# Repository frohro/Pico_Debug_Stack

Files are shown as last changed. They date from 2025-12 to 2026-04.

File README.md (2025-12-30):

# Raspberry Pi Pico Debug Stack

**A professional-grade hardware interposer for debugging, analyzing, and validating Raspberry Pi Pico projects.**
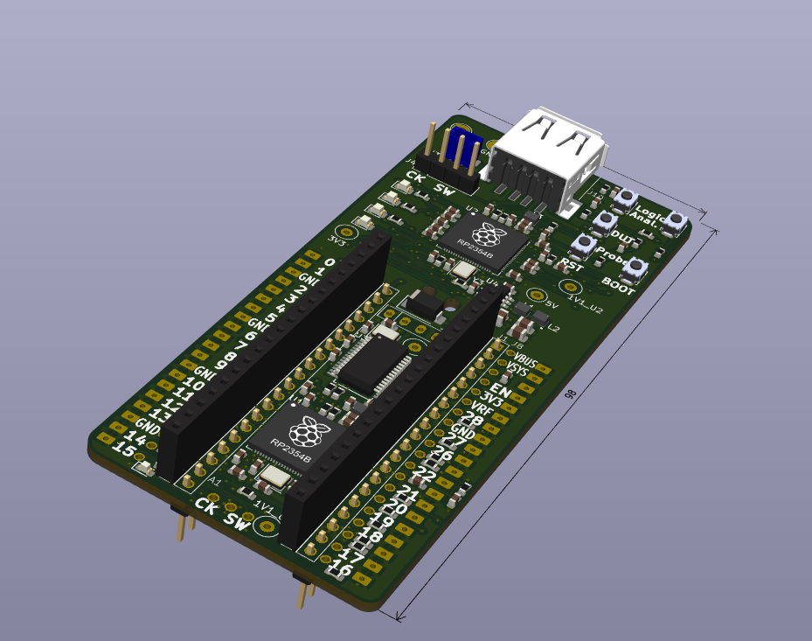
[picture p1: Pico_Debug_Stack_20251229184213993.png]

 

## Overview

The **Pico Debug Stack** is a "Man-in-the-Middle" Debug tool designed to eliminate the wiring mess typically associated with hardware debugging.

It acts as a hardware shim:
1.  Unplug your **Target Pico (DUT)** from your project motherboard.
2.  Plug the **Debug Stack** into your motherboard.
3.  Plug your **Target Pico** into the socket on top of the Debug Stack.

With a single USB connection to your PC, you instantly gain access to a full suite of hardware analysis tools connected directly to the DUT's pins, with no breadboards or jumper wires required.

## Key Features

*   **Integrated Logic Analysis:** Onboard **RP2354B** (with 2MB internal flash) running **[Dr. Gusman's Logic Analyzer](https://github.com/gusmanb/logicanalyzer)**. Capable of capturing high-speed signals (SPI, I2C, UART, I2S) from the DUT.
*   **Integrated Debug Probe:** Onboard **RP2354B** (with 2MB internal flash) running **[Yapicoprobe](https://github.com/rgrr/yapicoprobe)** (compatible with standard CMSIS-DAP/Picoprobe). Provides SWD debugging (Step, Pause, Breakpoints) and a UART console.
*   **Hardware Stimulus:** The Debug Probe is hardwired to the DUT's GPIOs via protection resistors, allowing you to inject signals or simulate sensors programmatically.
*   **Integrated USB Hub:** An onboard **GL850G USB Hub** manages all devices via a single USB-C connection. It provides:
    *   Internal link to the Logic Analyzer.
    *   Internal link to the Debug Probe.
    *   **Two auxiliary USB-A ports** (Stacked Connector J10) for connecting the Target Pico or other peripherals.
*   **Robust Power:** A **2A Synchronous Buck Converter (MT2492)** ensures ample power for the Debug Stack and the Target Pico.
*   **Universal Compatibility:** Supports Raspberry Pi Pico, Pico W, Pico 2, and Pico 2W.
*   **Safety First:** 330Ω series resistors protect all GPIO connections between the Analyzer, Probe, and DUT.

## Hardware Architecture

The board consists of three main controllers:

1.  **U1 (Logic Analyzer):** An **RP2354B** dedicated to monitoring DUT GPIOs.
2.  **U2 (Debug Probe):** An **RP2354B** handling SWD communication and Stimulus generation.
3.  **U3 (USB Hub):** A **GL850G** providing connectivity to U1, U2, and the auxiliary ports.

### The Stack Physical Layout
*   **Top:** Socket for DUT (Pico H footprint).
*   **Middle:** The Debug Stack PCB (Analyzer + Probe + Hub).
*   **Bottom:** Male Headers (plugs into your original project).

### Important Note on DUT USB
The **Target Pico's USB data lines (D+/D-)** are **NOT** routed through the stack headers to the Hub automatically.
*   **Debug/Analysis:** Works instantly via the shim headers.
*   **Target USB Data:** If your Target Pico runs code that requires USB connectivity (e.g., TinyUSB), you must use a short USB cable to connect the Target Pico's USB port to one of the **Auxiliary USB-A ports** on the Debug Stack.

## Software & Firmware

To use this board, the onboard RP2354s must be flashed with the following firmware:

*   **Logic Analyzer (U1):** [Download Dr. Gusman's LogicAnalyzer Firmware](https://github.com/gusmanb/logicanalyzer) Ensure you use the RP2350 build for this board.  Instead of shorting GPIO0 and GPIO1 to do burst capture, GPIO30 is connected to GPIO29.  These are  settings in the LogicAnalyzer_BoardSettings.h.  I will put the .uF2 file for this LogicAnalyzer on GitHub.
*   **Debug Probe (U2):** [Download Yapicoprobe Firmware](https://github.com/rgrr/yapicoprobe) (or the official Raspberry Pi `debugprobe` firmware).  

## Using the Stimulus Features

One of the most powerful features of this board is the ability to use the **Debug Probe (U2)** to "exercise" the **DUT**. Because the Probe's GPIOs are wired to the DUT's GPIOs (via 330Ω resistors), you can write software for the Probe to simulate external hardware.

### Concept
Instead of physically wiring a button or a sensor to your project to test it, you can tell the Probe to "pull Pin 15 High" or "Send a pulse on Pin 2".

### Example: Writing Stimulus Software
*The following is a MicroPython example. You can run this on the **Debug Probe (U2)** to test the DUT.*

**Scenario:** Your DUT code waits for a button press on `GP15` and then blinks an LED. You want to automate testing this.

1.  Flash **MicroPython** onto the **Debug Probe (U2)** (temporarily replacing the probe firmware).
2.  Run this script on U2:

```python
import machine
import time

# Note: Check the schematic for the specific mapping between Probe GPIO and DUT GPIO
# The mapping is scrambled to optimize PCB routing.
stimulus_pin = machine.Pin(15, machine.Pin.OUT) 

print("Starting Stimulus Test...")

while True:
    print("Simulating Button Press (High)...")
    stimulus_pin.value(1)
    time.sleep(0.5) # Hold for 500ms
    
    print("Simulating Release (Low)...")
    stimulus_pin.value(0)
    time.sleep(2.0) # Wait 2 seconds before next test
```

### Advanced Stimulus (C/C++)
For high-speed protocol simulation (e.g., simulating an SPI sensor sending data to the DUT), you should write a C/C++ program for the Probe using the Pico SDK.

**Skeleton Code for `main.c` on the Probe:**

```c
#include "pico/stdlib.h"
#include "hardware/gpio.h"

// Map of Probe Pins to DUT Pins (Refer to Schematic)
#define STIMULUS_PIN_A  10 
#define STIMULUS_PIN_B  11

void generate_fake_sensor_data() {
    // Bit-bang a protocol or toggle pins
    gpio_put(STIMULUS_PIN_A, 1);
    sleep_us(10);
    gpio_put(STIMULUS_PIN_A, 0);
}

int main() {
    stdio_init_all();
    
    gpio_init(STIMULUS_PIN_A);
    gpio_set_dir(STIMULUS_PIN_A, GPIO_OUT);

    while (1) {
        // Wait for a command from PC, or just run a loop
        generate_fake_sensor_data();
        sleep_ms(100);
    }
}
```
## Kicad Project
This Kicad project uses the CDFER [JLCPCB Library](https://github.com/CDFER/JLCPCB-Kicad-Library).  If you don't install it, the rules checker in EESchema will bark at you.  After installing it, you have to quit Kicad and start again.

## Setup Instructions

1.  **Assembly:** Ensure U1 and U2 are flashed with their respective firmware.
2.  **Connection:** Plug the board into your PC via the USB-C port labeled `USB IN`.
3.  **Drivers:**
    *   **Analyzer:** Open Dr. Gusman's software (or Sigrok PulseView) and connect to the Logic Analyzer device.
    *   **Probe:** In VS Code (or your IDE), select the CMSIS-DAP interface for the Debug Probe.
4.  **Hardware Install:**
    *   Plug the Debug Stack into your project board.
    *   Plug your Pico H (DUT) into the socket on the Debug Stack.

## License

Designed by Rob Frohne, Walla Walla University.
Open Source Hardware.

---
*Note: This design uses RP2354B chips. Ensure your software toolchain supports the RP2350 architecture.*

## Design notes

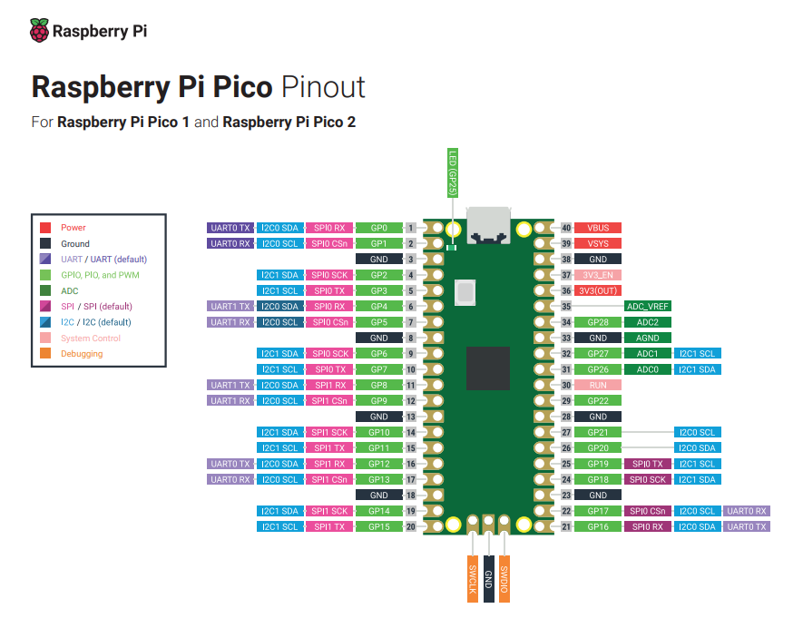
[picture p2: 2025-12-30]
rpi-lib-kicad/pico_pinout.png

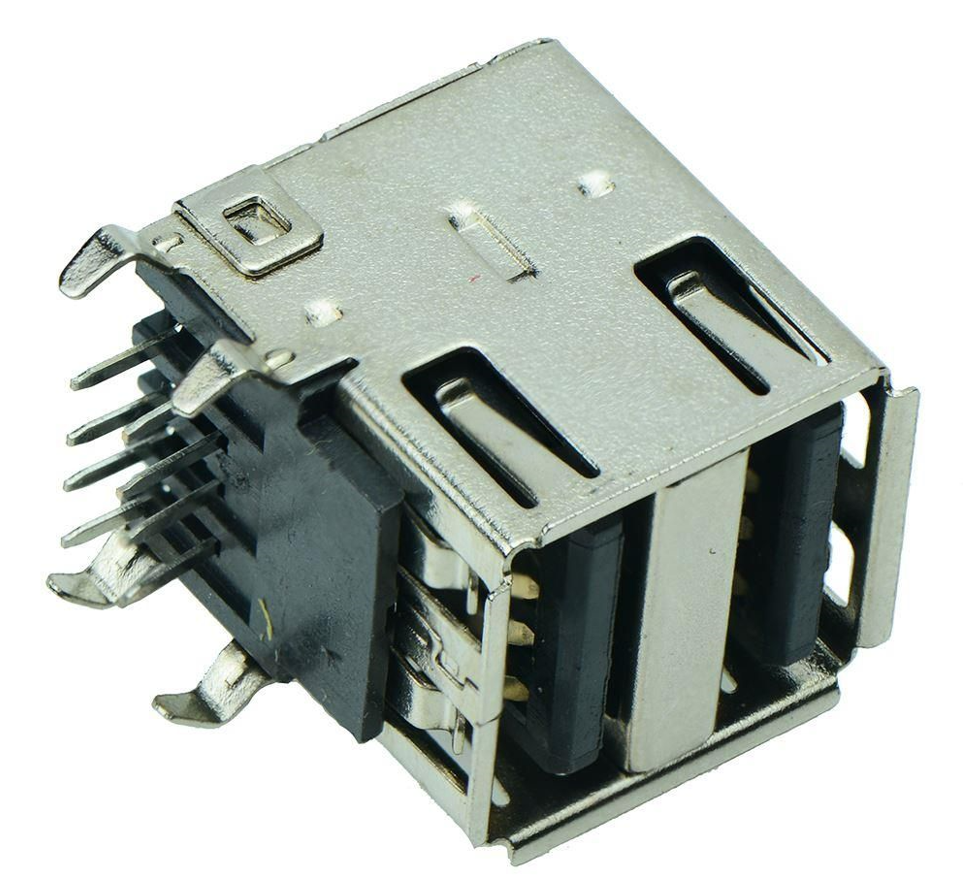
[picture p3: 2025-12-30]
rpi-lib-kicad/dual-usb-2-0-connector-type-a-1.snapshot.3/Capture.PNG

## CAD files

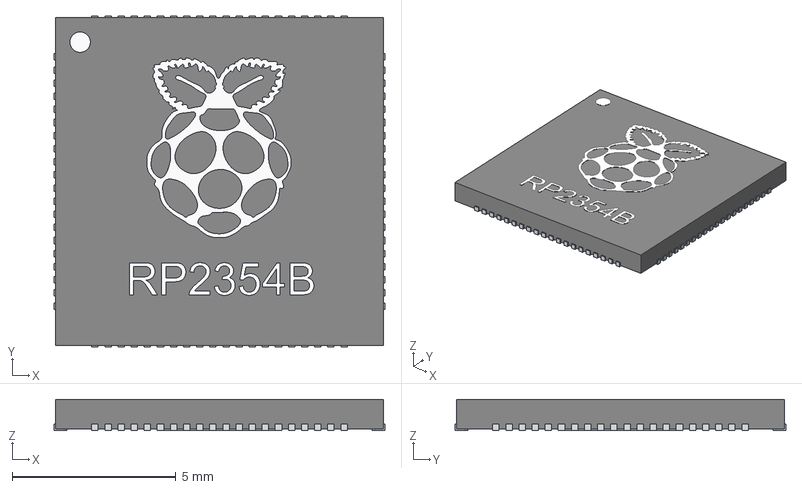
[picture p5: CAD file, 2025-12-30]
rp2350-1.snapshot.10/RP2354B.stp
10.1 x 10.1 x 0.96 mm

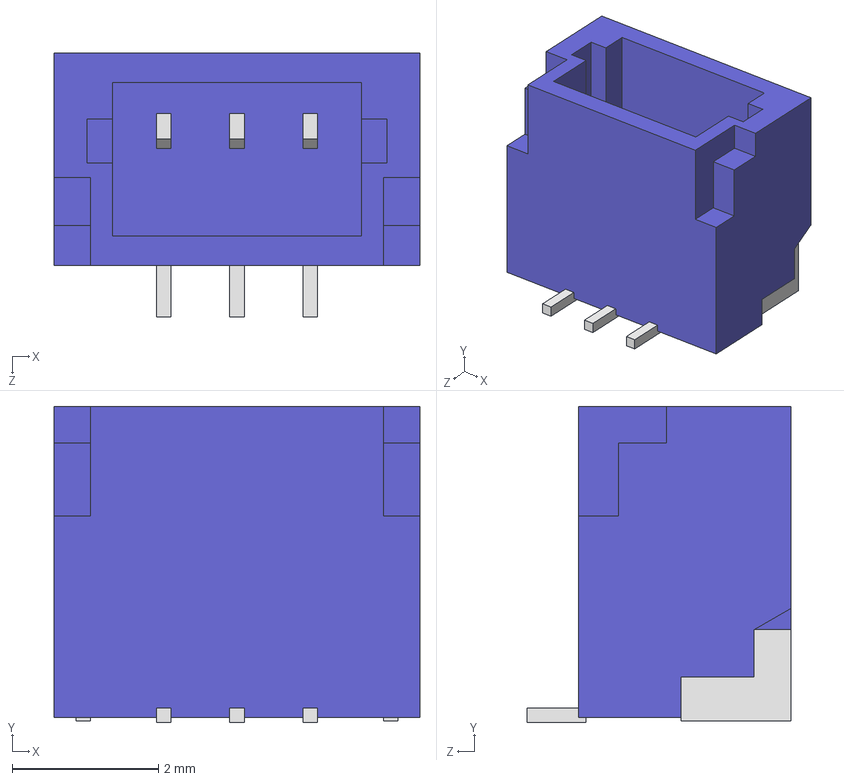
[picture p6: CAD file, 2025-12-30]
rpi-lib-kicad/BM03B-SRSS-TB.STEP
5.00 x 4.32 x 3.60 mm

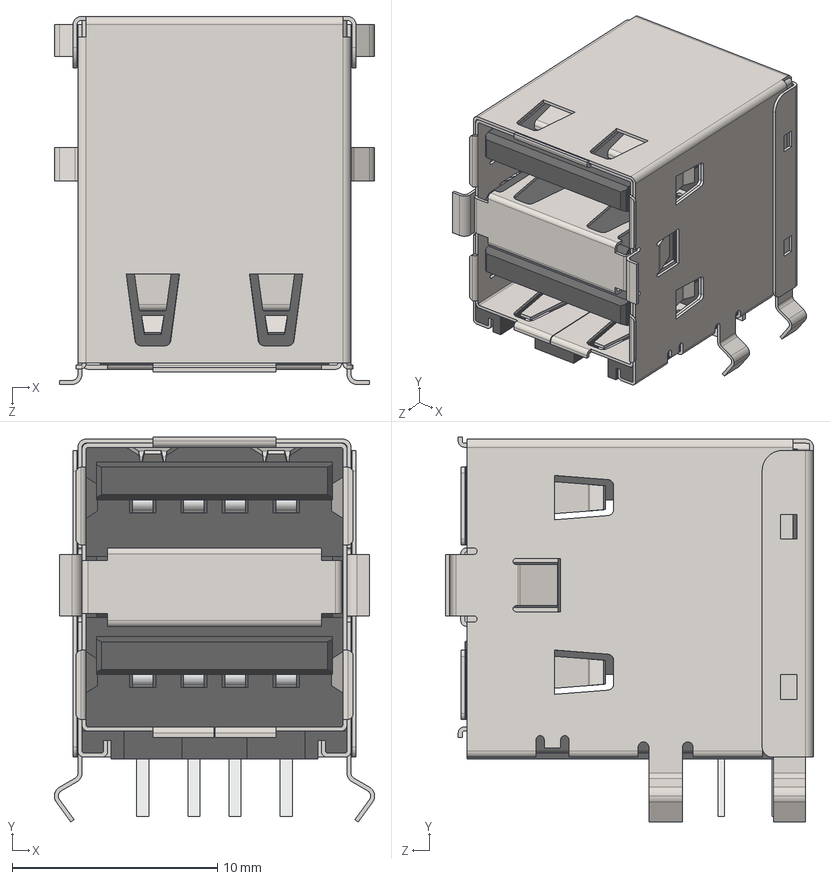
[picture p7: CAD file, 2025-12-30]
rpi-lib-kicad/dual-usb-2-0-connector-type-a-1.snapshot.3/usb double.STEP
15.6 x 18.7 x 17.9 mm

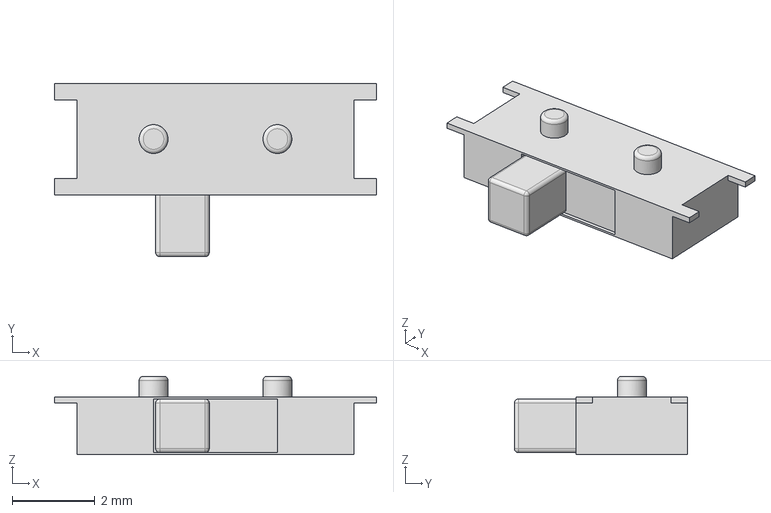
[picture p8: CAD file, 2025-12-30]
rpi-lib-kicad/msk12c02.step
7.80 x 4.20 x 1.90 mm

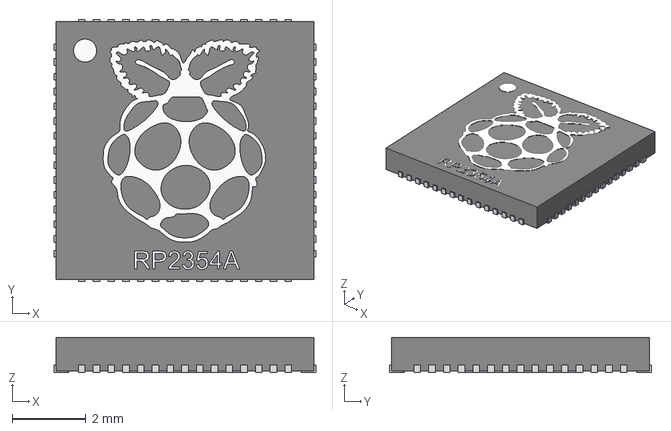
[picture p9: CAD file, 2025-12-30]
rp2350-1.snapshot.10/RP2354A.stp
7.10 x 7.10 x 0.96 mm

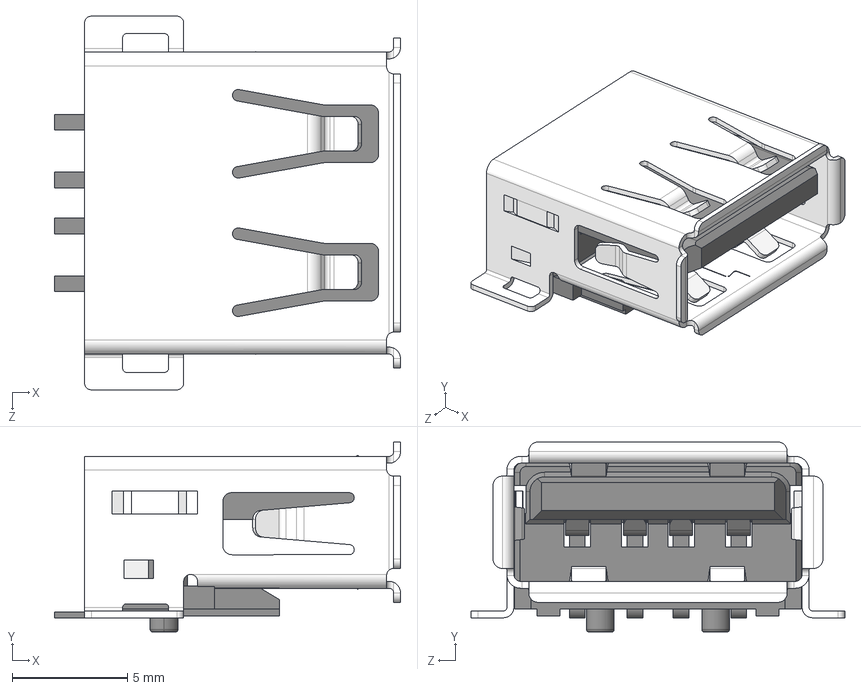
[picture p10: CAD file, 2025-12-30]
rpi-lib-kicad/UJ2-AH-1-SMT-TR.step
15.0 x 8.23 x 16.2 mm

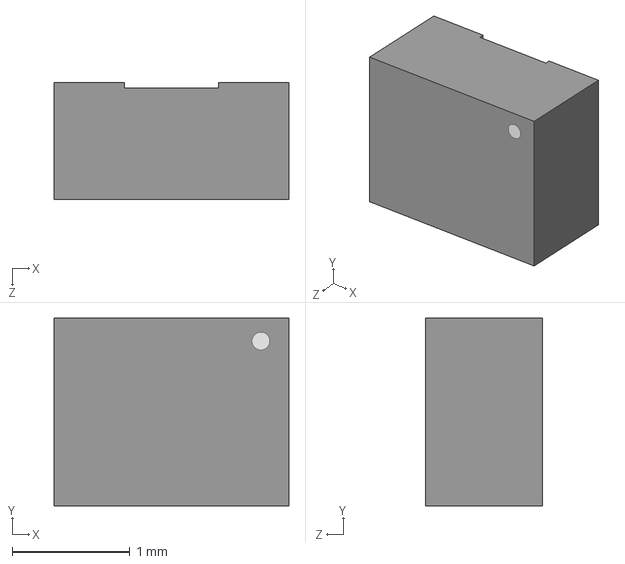
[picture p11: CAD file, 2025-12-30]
rpi-lib-kicad/AOTA-B201610S3R3-101-T.stp
2.00 x 1.60 x 1.00 mm

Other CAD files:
rp2350-1.snapshot.10/RP2350B.stp
rp2350-1.snapshot.10/RP2350A.stp
rpi-lib-kicad/dual-usb-2-0-connector-type-a-1.snapshot.3/usb double.SLDPRT

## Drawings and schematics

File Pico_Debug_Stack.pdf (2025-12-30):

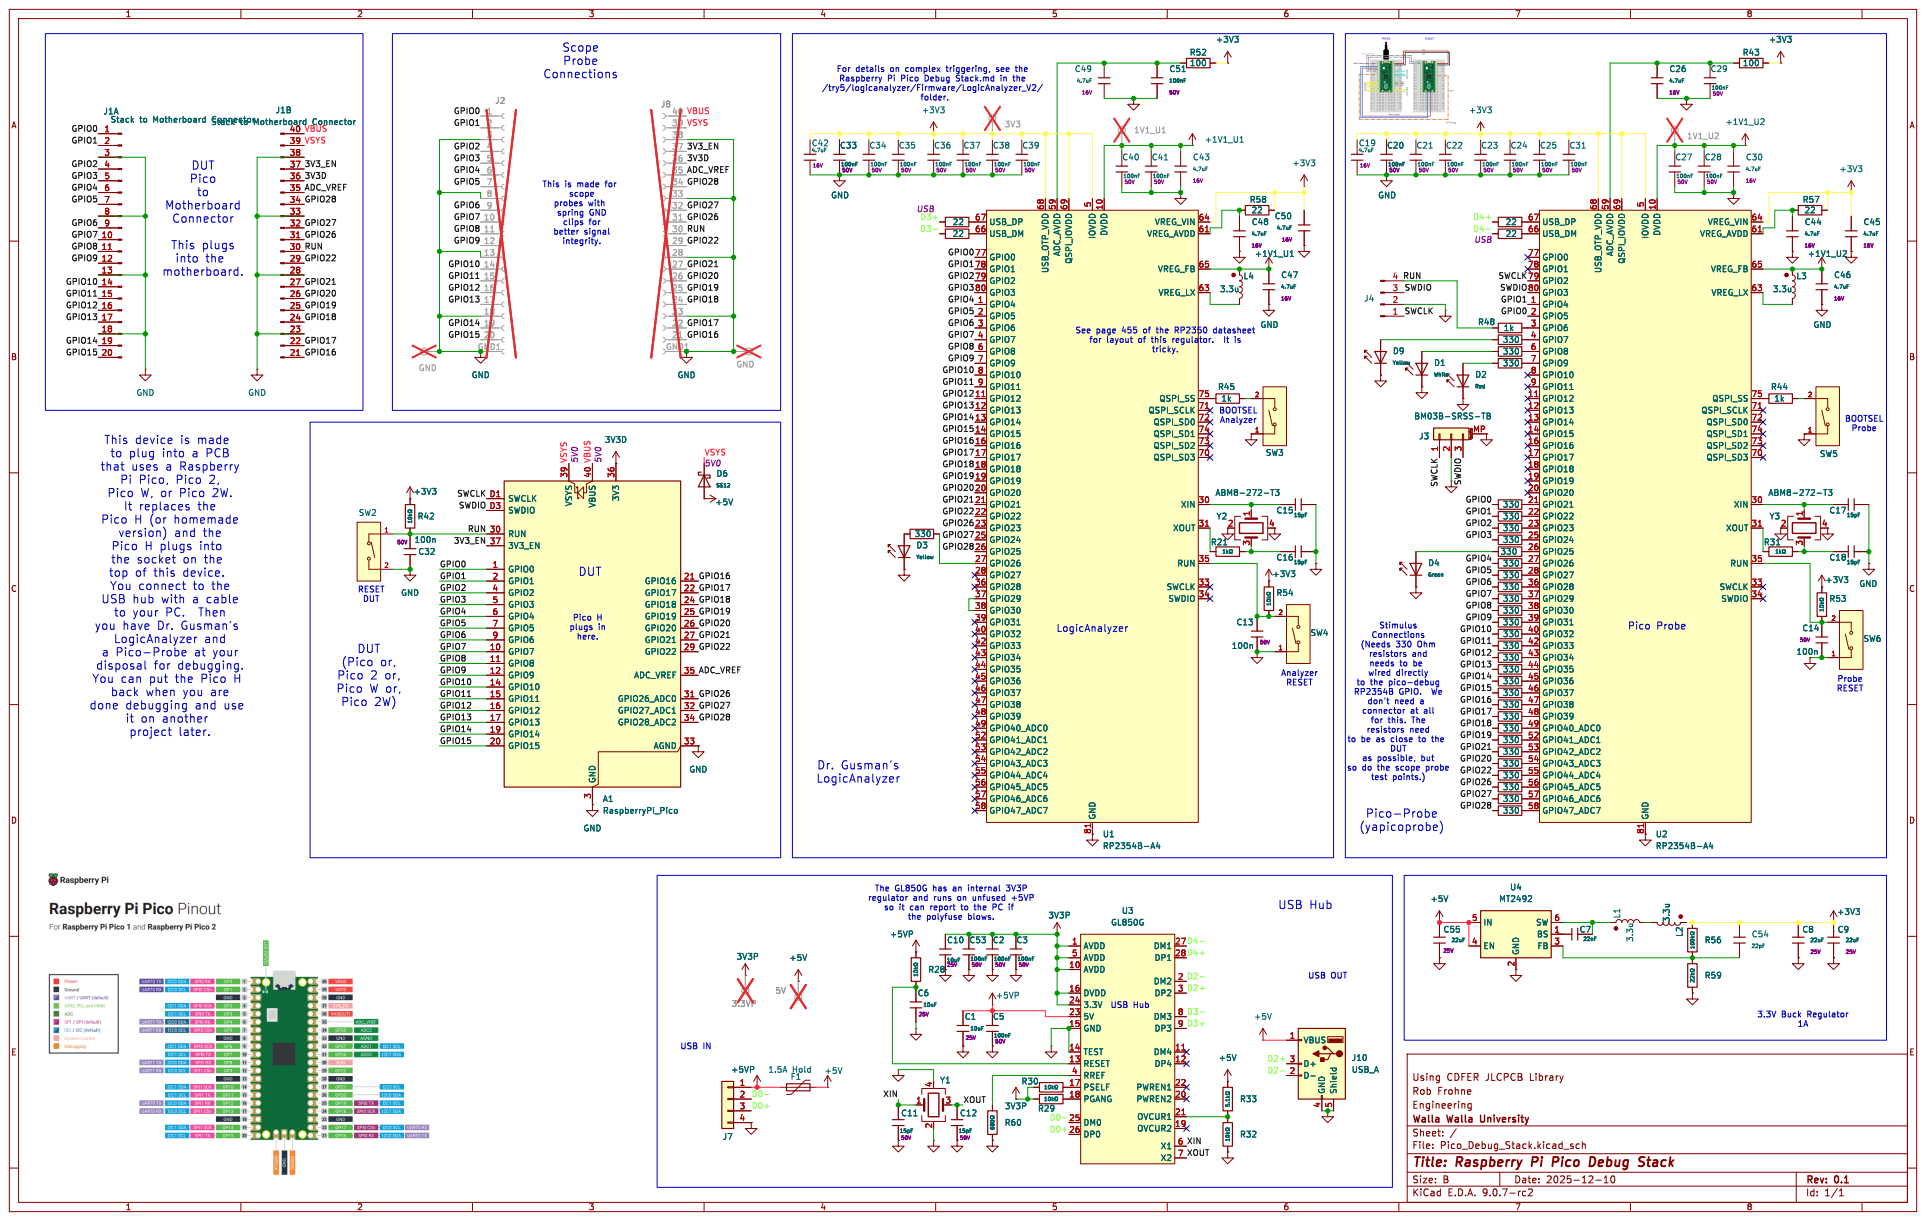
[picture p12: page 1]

folder. This is made for scope

probes with
spring GND
clips for better signal

5 DVDD 10 VREG_VIN 64 VREG_AVDD61 VREG_FB 65 VREG_LX 63 QSPI_SS 75 QSPI_SCLK 71 QSPI_SD0 72 QSPI_SD1 74 QSPI_SD2 73 QSPI_SD3 70 XIN 30 XOUT 31 RUN 35 SWCLK 33 SWDIO 34 GND 81 C16 15pF GNDGND

5 DVDD 10 VREG_VIN 64 VREG_AVDD61 VREG_FB 65 VREG_LX 63 QSPI_SS 75 QSPI_SCLK 71 QSPI_SD0 72 QSPI_SD1 74 QSPI_SD2 73 QSPI_SD3 70 XIN 30 XOUT 31 RUN 35 SWCLK 33 SWDIO 34 GND 81 U1 RP2354B-A4

See page 455 of the RP2350 datasheet

This device is made
to plug into a PCB
that uses a Raspberry
Pi Pico, Pico 2,
Pico W, or Pico 2W.
It replaces the
Pico H (or homemade

version) and the
Pico H plugs into
the socket on the
top of this device.
You connect to the
USB hub with a cable
to your PC. Then
you have Dr. Gusman's

3.3V Buck Regulator 1A Pico Probe Pico-Probe

disposal for debugging.
You can put the Pico H
back when you are
it on another
project later.

(Needs 330 Ohm
needs to be wired directly

to be as close to the DUT

so it can report to the PC if

File: Pico_Debug_Stack.kicad_sch Sheet: / Walla Walla University

Id: 1/1 Title: Raspberry Pi Pico Debug Stack

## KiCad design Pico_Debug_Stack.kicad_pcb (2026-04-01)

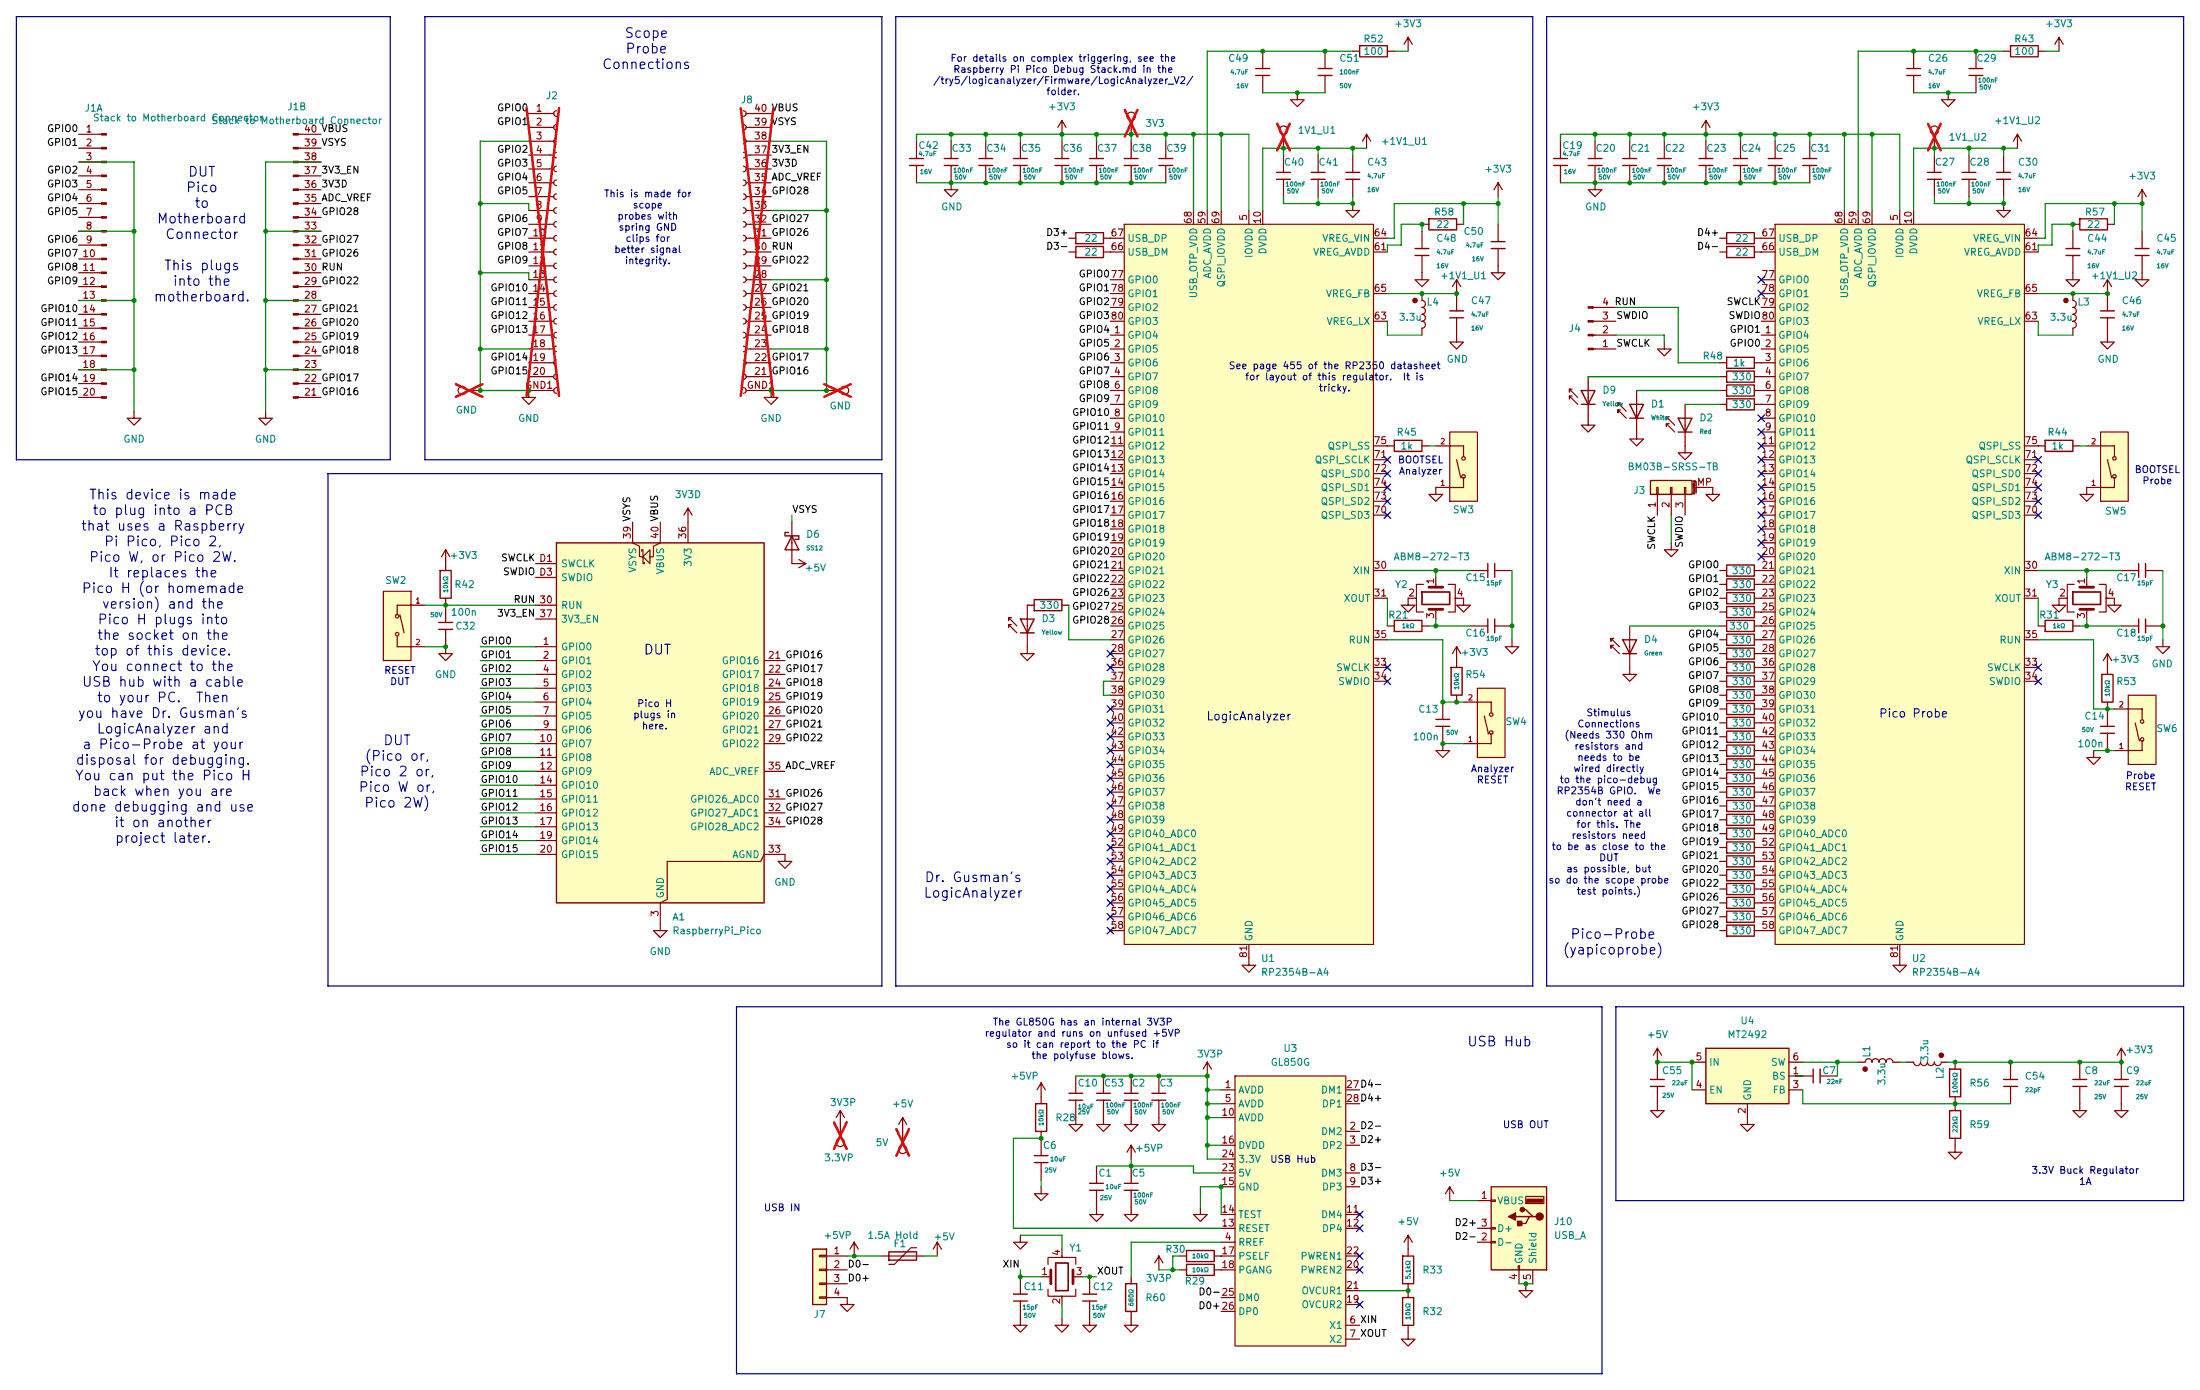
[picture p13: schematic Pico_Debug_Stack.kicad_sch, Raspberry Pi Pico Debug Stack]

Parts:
1V1_U1: 1V1_U1; TestPoint_Loop_D2.60mm_Drill0.9mm_Beaded; not fitted
A1: RaspberryPi_Pico; Pico Connector_SW
C1, C6, C10: 10uF; C_0603; Voltage Rated 25V; Tolerance ±20%; Part CL10A106MA8NRNC; LCSC C96446
C2, C3, C5, C20, C21, C22, C23, C24, C25, C27, C28, C29, C31, C33, C34, C35, C36, C37, C38, C39, C40, C41, C51, C53: 100nF; C_0603; Voltage Rated 50V; Tolerance ±10%; Part CC0603KRX7R9BB104; LCSC C14663
C7: 22nF; C_0603; Voltage Rated 50V; Tolerance ±10%; Part CL10B223KB8NNNC; LCSC C21122
C8, C9, C55: 22uF; C_0805; Voltage Rated 25V; Tolerance ±20%; Part CL21A226MAQNNNE; LCSC C45783
C11, C12, C15, C16, C17, C18: 15pF; C_0603; Voltage Rated 50V; Tolerance ±5%; Part CL10C150JB8NNNC; LCSC C1644
C13, C14, C32: 100n; C_0603; Voltage Rated 50V; Tolerance ±10%; Part CC0603KRX7R9BB104; LCSC C14663
C19, C26, C30, C42, C43, C44, C45, C46, C47, C48, C49, C50: 4.7uF; C_0603; Voltage Rated 16V; Tolerance ±10%; Part CL10A475KO8NNNC; LCSC C19666
C54: 22pF; C_0603; Voltage Rated 50V; Tolerance ±5%; Part CL10C220JB8NNNC; LCSC C1653
D1: White; D_0805; Part KT-0805W; LCSC C34499
D2: Red; D_0805; Forward Voltage (VF) 1.6V~2.6V; Part NCD0805R1; LCSC C84256
D3: Yellow; D_0603; Forward Voltage (VF) 1.6V~2.6V; Part NCD0603Y2; LCSC C89811
D4: Green; D_0805; Part KT-0805G; LCSC C2297
D6: SS12; D_SMA; Part SS12; LCSC C18199177
D9: Yellow; D_0805; Part KT-0805Y; LCSC C2296
F1: 1.5A Hold; Fuse_1206_3216Metric; LCSC C495353
J1: Stack to Motherboard Connector; Pico Connector; LCSC C5156618
J2: Scope_TP; Scope_Probe_GND_SPRING_01x20; not fitted
J3: BM03B-SRSS-TB; JST_SH_BM03B-SRSS-TB_1x03-1MP_P1.00mm_Vertical; MPN BM03B-SRSS-TB; LCSC C160389
J4: Conn_01x04_Pin; PinHeader_1x04_P2.54mm_Vertical
J7: Conn_01x04; SIP-4
J8: Scope_TP_21-40; Scope_Probe_GND_SPRING_01x21-40; not fitted
J10: USB_A; USB_AF_SMD; LCSC C112455
L1, L2, L3, L4: 3.3u; L_pol_2016; MPN MLP2016H3R3MT0S1 (substituted AOTA-B201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; LCSC C42411119
R1, R8, R9, R12, R13, R14, R15, R16, R17, R18, R19, R20, R22, R23, R24, R25, R26, R27, R34, R35, R36, R37, R38, R39, R40, R41, R46, R47, R49, R50, R51: 330; R_0603; Overload Voltage (Max) 75V; Tolerance ±1%; Part 0603WAF3300T5E; LCSC C23138
R4, R5, R6, R7: 22; R_0603; Overload Voltage (Max) 75V; Tolerance ±1%; Part 0603WAF220JT5E; LCSC C23345
R21, R31: 1kΩ; R_0603; Overload Voltage (Max) 75V; Tolerance ±1%; Part 0603WAF1001T5E; LCSC C21190
R28, R29, R30, R32, R42, R53, R54: 10kΩ; R_0603; Overload Voltage (Max) 75V; Tolerance ±1%; Part 0603WAF1002T5E; LCSC C25804
R33: 5.1kΩ; R_0603; Overload Voltage (Max) 75V; Tolerance ±1%; Part 0603WAF5101T5E; LCSC C23186
R43, R52: 100; R_0603; Tolerance ±1%; Overload Voltage (Max) 75V; MPN RC0402FR-07100RL; LCSC C22775
R44, R45, R48: 1k; R_0603; Tolerance ±1%; Overload Voltage (Max) 75V; MPN RC0402FR-071KL; LCSC C21190
R56: 100kΩ; R_0603; Overload Voltage (Max) 75V; Tolerance ±1%; Part 0603WAF1003T5E; LCSC C25803
R57, R58: 22; R_0603; Tolerance ±1%; Overload Voltage (Max) 75V; MPN RC0402FR-0727RL; LCSC C23345
R59: 22kΩ; R_0603; Overload Voltage (Max) 75V; Tolerance ±1%; Part 0603WAF2202T5E; LCSC C31850
R60: 680Ω; R_0603; Overload Voltage (Max) 75V; Tolerance ±1%; Part 0603WAF6800T5E; LCSC C23228
SW2, SW3, SW4, SW5, SW6: Tactile Button, 160gf; SW_TS-1088-AR02016; Voltage Rating (Dc) 12V; Part TS-1088-AR02016; LCSC C720477
TP1, TP2: GND; TestPoint_Loop_D2.54mm_Drill1.5mm_Beaded; not fitted
TP3: 5V; TestPoint_Loop_D2.50mm_Drill1.0mm_LowProfile; not fitted
TP4: 3V3; TestPoint_Loop_D2.60mm_Drill0.9mm_Beaded; not fitted
TP5: 1V1_U2; TestPoint_Loop_D2.60mm_Drill0.9mm_Beaded; not fitted
TP6: 3.3VP; TestPoint_Loop_D2.60mm_Drill0.9mm_Beaded; not fitted
U1, U2: RP2354B-A4; QFN-80-1EP_10x10mm_P0.4mm_EP3.4x3.4mm_ThermalVias; LCSC C39843328
U3: GL850G; SSOP-28_5.3x10.2mm_P0.65mm; LCSC C136617
U4: MT2492; SOT-23-6; LCSC C89358
Y1, Y2, Y3: ABM8-272-T3; Crystal_SMD_3225-4Pin_3.2x2.5mm; MPN ABM8-272-T3; LCSC C20625731

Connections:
3V3D: A1.36 (3V3), J1.36, J8.36
3V3P: C2.1, C3.1, C10.1, C53.1, R29.1, R30.1, TP6.1, U3.1 (AVDD), U3.5 (AVDD), U3.10 (AVDD), U3.16 (DVDD), U3.24 (3.3V)
+1V1_U1: 1V1_U1.1, C40.1, C41.1, C43.1, C47.1, L4.1, U1.10 (DVDD), U1.32 (DVDD), U1.51 (DVDD), U1.65 (VREG_FB)
+1V1_U2: C27.1, C28.1, C30.1, C46.1, L3.1, TP5.1, U2.10 (DVDD), U2.32 (DVDD), U2.51 (DVDD), U2.65 (VREG_FB)
+3V3: C8.1, C9.1, C19.1, C20.1, C21.1, C22.1, C23.1, C24.1, C25.1, C31.1, C33.1, C34.1, C35.1, C36.1, C37.1, C38.1, C39.1, C42.1, C45.1, C50.1, C54.1, L2.1, R42.1, R43.2, R52.2, R53.1, R54.1, R56.1, R57.2, R58.2, TP4.1, U1.5 (IOVDD), U1.15 (IOVDD), U1.24 (IOVDD), U1.29 (IOVDD), U1.41 (IOVDD), U1.50 (IOVDD), U1.60 (IOVDD), U1.64 (VREG_VIN), U1.68 (USB_OTP_VDD), U1.69 (QSPI_IOVDD), U1.76 (IOVDD), U2.5 (IOVDD), U2.15 (IOVDD), U2.24 (IOVDD), U2.29 (IOVDD), U2.41 (IOVDD), U2.50 (IOVDD), U2.60 (IOVDD), U2.64 (VREG_VIN), U2.68 (USB_OTP_VDD), U2.69 (QSPI_IOVDD), U2.76 (IOVDD)
+5V: C55.1, D6.2, F1.2, J10.1 (VBUS), R33.1, TP3.1, U4.4 (EN), U4.5 (IN)
+5VP: C1.1, C5.1, F1.1, J7.1, R28.1, U3.23 (5V)
/3V3_EN: A1.37 (3V3_EN), J1.37, J8.37 (Pin_.7)
/ADC_VREF: A1.35 (ADC_VREF), J1.35, J8.35
/D0+: J7.3, U3.26 (DP0)
/D0-: J7.2, U3.25 (DM0)
/D2+: J10.3 (D+), U3.3 (DP2)
/D2-: J10.2 (D-), U3.2 (DM2)
/D3+: R6.1, U3.9 (DP3)
/D3-: R7.1, U3.8 (DM3)
/D4+: R4.1, U3.28 (DP1)
/D4-: R5.1, U3.27 (DM1)
/GPIO0: A1.1 (GPIO0), J1.1, J2.1, R8.1, U1.77 (GPIO0), U2.2 (GPIO5)
/GPIO1: A1.2 (GPIO1), J1.2, J2.2, R9.1, U1.78 (GPIO1), U2.1 (GPIO4)
/GPIO2: A1.4 (GPIO2), J1.4, J2.4, R12.1, U1.79 (GPIO2)
/GPIO3: A1.5 (GPIO3), J1.5, J2.5, R13.1, U1.80 (GPIO3)
/GPIO4: A1.6 (GPIO4), J1.6, J2.6, R14.1, U1.1 (GPIO4)
/GPIO5: A1.7 (GPIO5), J1.7, J2.7, R15.1, U1.2 (GPIO5)
/GPIO6: A1.9 (GPIO6), J1.9, J2.9, R16.1, U1.3 (GPIO6)
/GPIO7: A1.10 (GPIO7), J1.10, J2.10, R17.1, U1.4 (GPIO7)
/GPIO8: A1.11 (GPIO8), J1.11, J2.11, R18.1, U1.6 (GPIO8)
/GPIO9: A1.12 (GPIO9), J1.12, J2.12, R19.1, U1.7 (GPIO9)
/GPIO10: A1.14 (GPIO10), J1.14, J2.14, R20.1, U1.8 (GPIO10)
/GPIO11: A1.15 (GPIO11), J1.15, J2.15, R22.1, U1.9 (GPIO11)
/GPIO12: A1.16 (GPIO12), J1.16, J2.16, R23.1, U1.11 (GPIO12)
/GPIO13: A1.17 (GPIO13), J1.17, J2.17, R24.1, U1.12 (GPIO13)
/GPIO14: A1.19 (GPIO14), J1.19, J2.19, R25.1, U1.13 (GPIO14)
/GPIO15: A1.20 (GPIO15), J1.20, J2.20, R26.1, U1.14 (GPIO15)
/GPIO16: A1.21 (GPIO16), J1.21 (Pin_22), J8.21, R27.1, U1.16 (GPIO16)
/GPIO17: A1.22 (GPIO17), J1.22, J8.22, R34.1, U1.17 (GPIO17)
/GPIO18: A1.24 (GPIO18), J1.24, J8.24, R35.1, U1.18 (GPIO18)
/GPIO19: A1.25 (GPIO19), J1.25, J8.25, R36.1, U1.19 (GPIO19)
/GPIO20: A1.26 (GPIO20), J1.26, J8.26, R38.1, U1.20 (GPIO20)
/GPIO21: A1.27 (GPIO21), J1.27, J8.27, R37.1, U1.21 (GPIO21)
/GPIO22: A1.29 (GPIO22), J1.29, J8.29, R39.1, U1.22 (GPIO22)
/GPIO26: A1.31 (GPIO26_ADC0), J1.31, J8.31, R40.1, U1.23 (GPIO23)
/GPIO27: A1.32 (GPIO27_ADC1), J1.32, J8.32, R41.1, U1.25 (GPIO24)
/GPIO28: A1.34 (GPIO28_ADC2), J1.34, J8.34, R1.1, U1.26 (GPIO25)
/RUN: A1.30 (RUN), C32.1, J1.30, J4.4, J8.30, R42.2, R48.1, SW2.1 (A)
/SWCLK: A1.D1 (SWCLK), J3.1, J4.1, U2.79 (GPIO2)
/SWDIO: A1.D3 (SWDIO), J3.3, J4.3, U2.80 (GPIO3)
/VBUS: A1.40 (VBUS), J1.40, J8.40
/VSYS: A1.39 (VSYS), D6.1, J1.39, J8.39
/XIN: C11.1, U3.6 (X1), Y1.1
/XOUT: C12.1, U3.7 (X2), Y1.3
GND: A1.3 (GND), A1.8 (GND), A1.13 (GND), A1.18 (GND), A1.23 (GND), A1.28 (GND), A1.33 (AGND), A1.38 (GND), A1.D2 (GND), C1.2, C2.2, C3.2, C5.2, C6.2, C8.2, C9.2, C10.2, C11.2, C12.2, C13.2, C14.2, C15.2, C16.2, C17.2, C18.2, C19.2, C20.2, C21.2, C22.2, C23.2, C24.2, C25.2, C26.2, C27.2, C28.2, C29.2, C30.2, C31.2, C32.2, C33.2, C34.2, C35.2, C36.2, C37.2, C38.2, C39.2, C40.2, C41.2, C42.2, C43.2, C44.2, C45.2, C46.2, C47.2, C48.2, C49.2, C50.2, C51.2, C53.2, C55.2, D1.1, D2.1, D3.1, D4.1, D9.1, J1.3, J1.8, J1.13, J1.18, J1.23, J1.28, J1.33, J1.38, J2.3, J2.8, J2.13, J2.18, J2.GND1 (GND), J3.2, J3.MP (MountPin), J4.2, J7.4, J8.23, J8.28, J8.33, J8.38, J8.GND1 (GND), J10.4 (GND), J10.5 (Shield), R32.2, R59.2, R60.2, SW2.2 (B), SW3.1 (A), SW4.1 (A), SW5.1 (A), SW6.1 (A), TP1.1, TP2.1, U1.62 (VREG_PGND), U1.81 (GND), U2.62 (VREG_PGND), U2.81 (GND), U3.14 (TEST), U3.15 (GND), U4.2 (GND), Y1.2, Y1.4, Y2.2, Y2.4, Y3.2, Y3.4
unnamed: C16.1, R21.2, Y2.3
unnamed: C18.1, R31.2, Y3.3
unnamed: D1.2, R50.1
unnamed: D2.2, R51.1
unnamed: D3.2, R46.1
unnamed: D4.2, R47.2
unnamed: D9.2, R49.1
unnamed: L1.2, L2.2
unnamed: R45.2, SW3.2 (B)
unnamed: C13.1, R54.2, SW4.2 (B), U1.35 (RUN)
unnamed: R44.2, SW5.2 (B)
unnamed: C14.1, R53.2, SW6.2 (B), U2.35 (RUN)
unnamed: C49.1, C51.1, R52.1, U1.59 (ADC_AVDD)
unnamed: R46.2, U1.27 (GPIO26)
unnamed: U1.37 (GPIO29), U1.38 (GPIO30)
unnamed: R45.1, U1.75 (QSPI_SS)
unnamed: R7.2, U1.66 (USB_DM)
unnamed: R6.2, U1.67 (USB_DP)
unnamed: C48.1, R58.1, U1.61 (VREG_AVDD)
unnamed: L4.2, U1.63 (VREG_LX)
unnamed: C15.1, U1.30 (XIN), Y2.1
unnamed: R21.1, U1.31 (XOUT)
unnamed: C26.1, C29.1, R43.1, U2.59 (ADC_AVDD)
unnamed: R48.2, U2.3 (GPIO6)
unnamed: R49.2, U2.4 (GPIO7)
unnamed: R50.2, U2.6 (GPIO8)
unnamed: R51.2, U2.7 (GPIO9)
unnamed: R8.2, U2.21 (GPIO21)
unnamed: R9.2, U2.22 (GPIO22)
unnamed: R12.2, U2.23 (GPIO23)
unnamed: R13.2, U2.25 (GPIO24)
unnamed: R47.1, U2.26 (GPIO25)
unnamed: R14.2, U2.27 (GPIO26)
unnamed: R15.2, U2.28 (GPIO27)
unnamed: R16.2, U2.36 (GPIO28)
unnamed: R17.2, U2.37 (GPIO29)
unnamed: R18.2, U2.38 (GPIO30)
unnamed: R19.2, U2.39 (GPIO31)
unnamed: R20.2, U2.40 (GPIO32)
unnamed: R22.2, U2.42 (GPIO33)
unnamed: R23.2, U2.43 (GPIO34)
unnamed: R24.2, U2.44 (GPIO35)
unnamed: R25.2, U2.45 (GPIO36)
unnamed: R26.2, U2.46 (GPIO37)
unnamed: R27.2, U2.47 (GPIO38)
unnamed: R34.2, U2.48 (GPIO39)
unnamed: R35.2, U2.49 (GPIO40_ADC0)
unnamed: R36.2, U2.52 (GPIO41_ADC1)
unnamed: R37.2, U2.53 (GPIO42_ADC2)
unnamed: R38.2, U2.54 (GPIO43_ADC3)
unnamed: R39.2, U2.55 (GPIO44_ADC4)
unnamed: R40.2, U2.56 (GPIO45_ADC5)
unnamed: R41.2, U2.57 (GPIO46_ADC6)
unnamed: R1.2, U2.58 (GPIO47_ADC7)
unnamed: R44.1, U2.75 (QSPI_SS)
unnamed: R5.2, U2.66 (USB_DM)
unnamed: R4.2, U2.67 (USB_DP)
unnamed: C44.1, R57.1, U2.61 (VREG_AVDD)
unnamed: L3.2, U2.63 (VREG_LX)
unnamed: C17.1, U2.30 (XIN), Y3.1
unnamed: R31.1, U2.31 (XOUT)
unnamed: R32.1, R33.2, U3.21 (OVCUR1)
unnamed: R29.2, U3.18 (PGANG)
unnamed: R30.2, U3.17 (PSELF)
unnamed: C6.1, R28.2, U3.13 (RESET)
unnamed: R60.1, U3.4 (RREF)
unnamed: C7.1, U4.1 (BS)
unnamed: C54.2, R56.2, R59.1, U4.3 (FB)
unnamed: C7.2, L1.1, U4.6 (SW)

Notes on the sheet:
Stimulus Connections (Needs 330 Ohm resistors and needs to be wired directly to the pico-debug RP2354B GPIO. We don't need a connector at all for this. The resistors need to be as close to the DUT as possible, but so do the scope probe test points.)
Dr. Gusman's LogicAnalyzer
USB IN
RESET DUT
DUT (Pico or, Pico 2 or, Pico W or, Pico 2W)
Pico H plugs in here.
LogicAnalyzer
USB Hub
BOOTSEL Analyzer
Analyzer RESET
Pico-Probe (yapicoprobe)
See page 455 of the RP2350 datasheet for layout of this regulator. It is tricky.
DUT
Pico Probe
Scope Probe Connections
This device is made to plug into a PCB that uses a Raspberry Pi Pico, Pico 2, Pico W, or Pico 2W. It replaces the Pico H (or homemade version) and the Pico H plugs into the socket on the top of this device. You connect to the USB hub with a cable to your PC. Then you have Dr. Gusman's LogicAnalyzer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
For details on complex triggering, see the Raspberry Pi Pico Debug Stack.md in the /try5/logicanalyzer/Firmware/LogicAnalyzer_V2/ folder.
3.3V Buck Regulator 1A
This is made for scope probes with spring GND clips for better signal integrity.
USB OUT
BOOTSEL Probe
Probe RESET
The GL850G has an internal 3V3P regulator and runs on unfused +5VP so it can report to the PC if the polyfuse blows.
DUT Pico to Motherboard Connector This plugs into the motherboard.

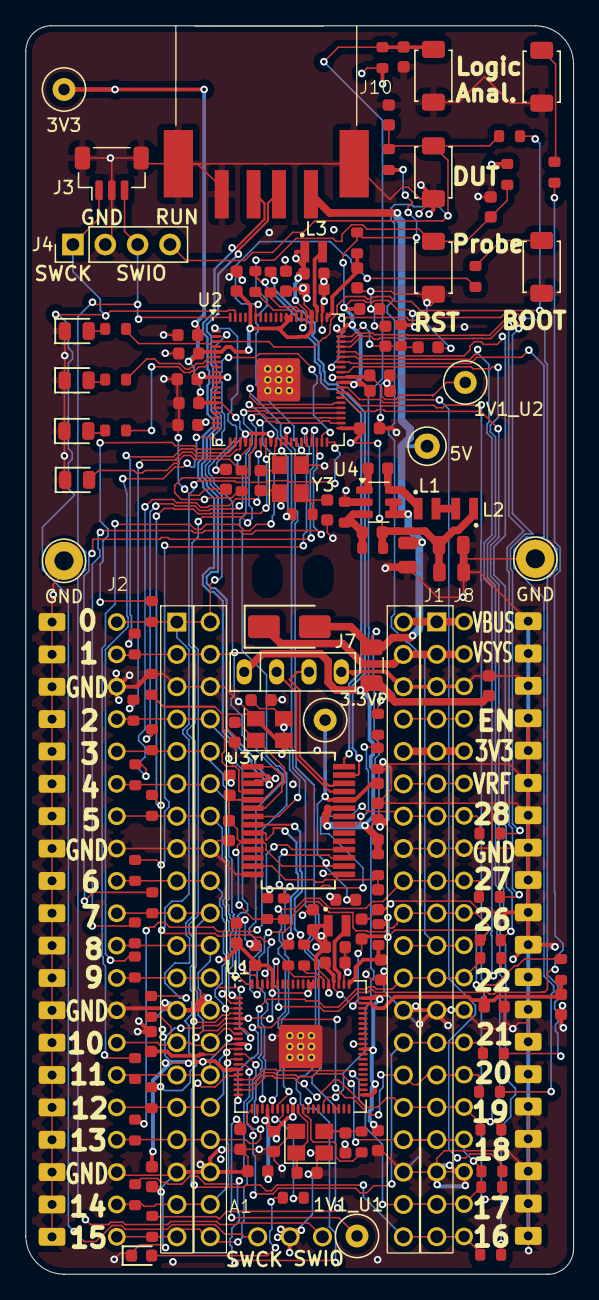
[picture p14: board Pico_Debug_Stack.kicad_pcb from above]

Board: 4 copper layers, 43.0 x 98.0 mm, 146 parts (1 on the bottom side), 120 nets.

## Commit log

2025-12-30 Replace wrong version with Version 0.1.1
    [Pico_Debug_Stack.kicad_pcb, Pico_Debug_Stack.kicad_sch]
2025-12-30 removed possibly obsolete schematic png
2026-01-11 Added a power plate for 1V1_U1 and 1V1_U2 to the power layer
    [Pico_Debug_Stack.kicad_pcb]
2026-04-01 Added holes for USB C socket
    Made this v0.1.2
    [Pico_Debug_Stack.kicad_pcb]
2026-04-14 note about USB C cables
    [Pico_Debug_Stack.kicad_sch]

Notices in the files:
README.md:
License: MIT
